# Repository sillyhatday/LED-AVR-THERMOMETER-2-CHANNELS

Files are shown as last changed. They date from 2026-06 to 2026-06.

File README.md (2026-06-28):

# 2 Channel Temperature Monitor

## 📢 Introduction

This came about as a break from the [nixie clock](https://github.com/sillyhatday/IN-12-NIXIE-CLOCK) project that was taking a long time to progress.

It is a 2 channel temperature monitor that is intended for inside and outside temperature monitoring.

>[!NOTE]
>While this project is functional, the code is a mess. It requires a rewrite.

---

## 🔨 Hardware

| Part Description | Part Number | Package | Quantity |
| --- | --- | --- | --- |
| Microcontroller | ATmega8A | DIP-28 | 1 |
| 4x 7 Segment Display | SR420561N | ?? | 1 |
| Voltage Reference | TL431 | TO-92-3 | 1 |
| Temperature Sensor | MCP9700 | TO-92 | 1 |
| Resistors | 470R | L6.3xD2.5xP10.16 | 8 |
| Resistors | 1K | L6.3xD2.5xP10.16 | 1 |
| Resistors | 10K | L6.3xD2.5xP10.16 | 7 |
| Capacitors | 20pF | D3.4xW2.1xP2.5 | 2 |
| Capacitors | 100nF | D3.0xW2.0xP2.5 | 3 |
| Capacitors | 1uF | ?? | 2 |
| Capacitors | 10uF | ?? | 1 |
| Buttons | PS-7054DVB-6PN | ?? | 2 |

---

## 📔 Functional Description

* The sensors used for temperature sensing are two MCP9700 packages. These are easy to use, not requiring external circuit conditioning. These can do negative temperatures without needing negative voltages, using a 500mV offset for 0c.

* For an air temperature monitor, the range does not need to be extreme. For the temperatures expected in Europe, -20c to 50c would be more than enough. For the most part things are between -3c and 35c. The range available for this project is -50c to 154.6c. A span of 204.6c.

* An accurate voltage refernce is needed to compare the sensor voltage with. For this the TL431 is used, it is another easy to use soloution. It has an output of 2.495v. For easy maths (and a large shortcut), having a reference voltage a multiple of the maximum ADC bits makes things simple. The 10-bit ADC is 0 - 1023. Setting the refrence voltage to 2.048v, through the use of a voltage divider network, is close enough to double.

* You may see that the finest change of temperature is 0.2c. That is 2048mV / 1023ADC = 2mV. The MCP9700 sensor output changes 10mV / 1c. As this setup requires 2mV per 1 ADC, 10mV / 2mV = 5. Finally, 5 ADC changes per 1c means, 1c / 5 = 0.2c. Should there not be a nice relation between voltage and ADC, the maths become more involved. Along the lines of: ADC reading > convert ADC to voltage > convert voltage to temperature. This can involve the use of floating point numbers. When getting to oversamlping, this complicates things further.

* The device has a single screen displaying temperature. It has two buttons. One for selecting which sensor is being displayed and the other to cycle through peak readings. These being: indoor high, indoor low, outdoor high & outdoor low. Peak readings are always being updated regardless of what is actively displayed on screen. These values can be reset by shorting the jumper connections on the back of the board. This can also be connected to a button if desired.

* I ended up using a mini 3 pin XLR connector for the outdoor temperature sensor, with the idea of it being removable should I wish to not use it, or I need to disconnect my outdoor sensor that isn't easily movable. I had the indoor sensor inside the case, the thought being it would help filter out any air current that could cause wild temperature reading changes. This did not work as the heat from the MCU was enough to ruin the accuracy. For accurate readings, the sensor should also be on a wire and positioned in the rood so that it is away from strong air currents. There is software averaging to reduce wild display changes.

>[!NOTE]
>The project code is honestly a mess. It's currently half rewritten in a better way using state machines. For now, this works well enough.

>[!TIP]
>Direct sunlight will heat up the outdoor sensor. A screen is required to help reduce this effect.

## ⚫ Progress

### 🟢 Done
- Build a functional temperature monitor that can read two channels
- Implement peak temperature readings and store them into EEPROM
- Add EEPROM check for knowing if to initialise memory space.
- Display text on screen when interacting with the button functions.

### 🟡 Working On
- Rewriting the whole code to use a traditional state machine based structure.
- Removing known bugs.

### ⚪ Next
- Nothing. A whole new project expanding on this one.

### 🔴 Known Bugs
- Temperatures over 100c corrupt adjacent memory space. Needs memory allocations moving.
- Flickering display when using the button functions. Race conditions, the rewrite will fix.
  
---

## Photos

### PCB Render

LED 7 Segment Temperature Monitor Front
LED 7 Segment Temperature Monitor Reart

### Final Concept
Temperature Monitor Enclosure angled front smol
Temperature Monitor Enclosure angled back smol

### Current Build



---

## Tools

- Tools: Arduino IDE 1.8.19 – MiniCore for ATMEGA8

---

## Links

🛍️ Inside Gadgets Shop: https://shop.insidegadgets.com <br>
📎 Inside Gadgets GitHub: https://github.com/insidegadgets <br>
📷 Inside Gadgets Insta: https://www.instagram.com/inside.gadgets <br>
🖇️ Bytendo Mods GitHub: https://github.com/bytendomods <br>
🐭 Bucket Mouse: https://github.com/Bucket-Mouse <br>
🛒 Natalie Shop: https://nataliethenerd.com/ <br>
🤓 Natalie GitHub: https://github.com/natalie-lang/natalie <br>
💡 Danyk Project 1: https://danyk.cz/avr_tep2_en.html <br>
🌡️ Danyk Project 2: https://danyk.cz/avr_tep_en.html <br>

---

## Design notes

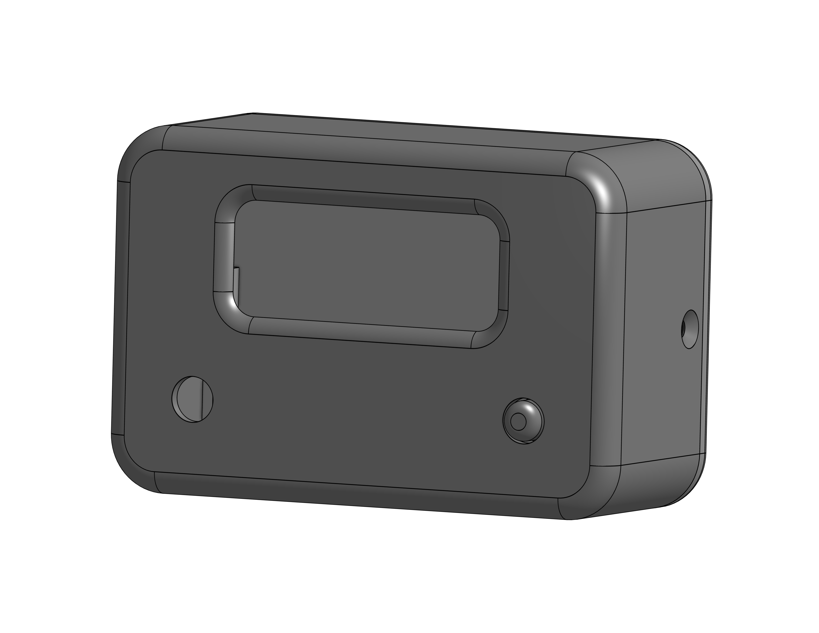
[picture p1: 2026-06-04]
PHOTOS & RENDERS/Temperature Monitor Enclosure angled front.png

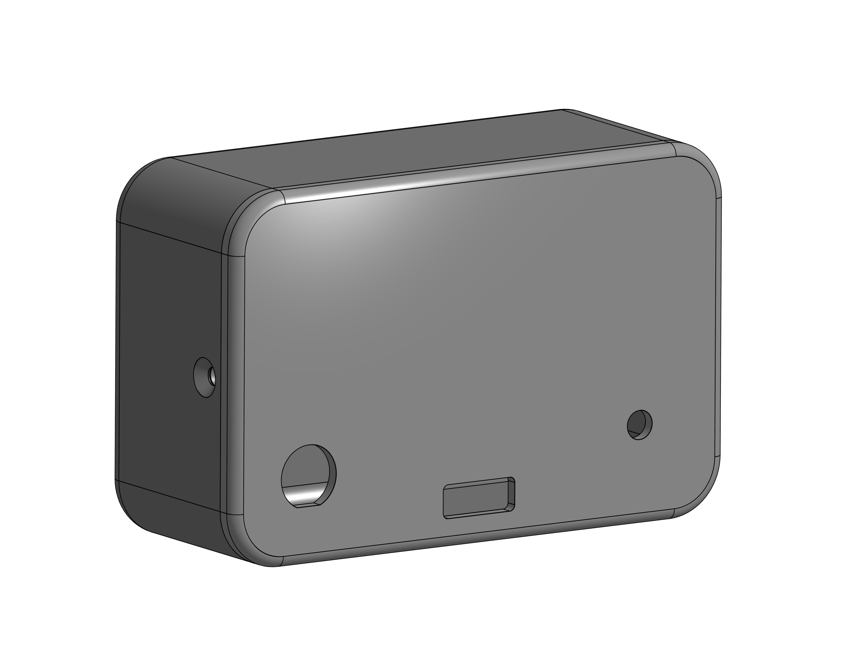
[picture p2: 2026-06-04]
PHOTOS & RENDERS/Temperature Monitor Enclosure angled back.png

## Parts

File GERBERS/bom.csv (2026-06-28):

Designator | Footprint | Quantity | Value | LCSC Part #
C1, C2 | C_Disc_D5.0mm_W2.5mm_P2.50mm | 2 | 100nF
C3 | CP_Radial_D5.0mm_P2.50mm | 1 | 47uF
C4, C5 | C_Disc_D5.0mm_W2.5mm_P2.50mm | 2 | 20pF
C6, C7 | CP_Radial_D4.0mm_P2.00mm | 2 | 1uF
J1, J2 | PinHeader_1x03_P2.54mm_Vertical | 2 | Conn_01x03_Pin
Q1, Q2, Q3, Q4 | TO-92_Inline | 4 | NPN
R1, R12, R2, R3, R4, R5, R6, R7 | R_Axial_DIN0207_L6.3mm_D2.5mm_P10.16mm_Horizontal | 8 | 470R
R10, R11, R13, R14, R8 | R_Axial_DIN0207_L6.3mm_D2.5mm_P10.16mm_Horizontal | 5 | 10K
R9 | R_Axial_DIN0207_L6.3mm_D2.5mm_P10.16mm_Horizontal | 1 | 4K7
SW1, SW2 | SHOU HAN 5.8 WSPT | 2 | SW_DPST
U1 | DIP-28_W7.62mm | 1 | ATmega8A-P
U2 | CA56-12EWA | 1 | CA56-12EWA
U3 | TO-92_Inline | 1 | TL431D
U4, U5 | TO-92_Inline | 2 | MCP9700
Y1 | Crystal_HC18-U_Vertical | 1 | Crystal

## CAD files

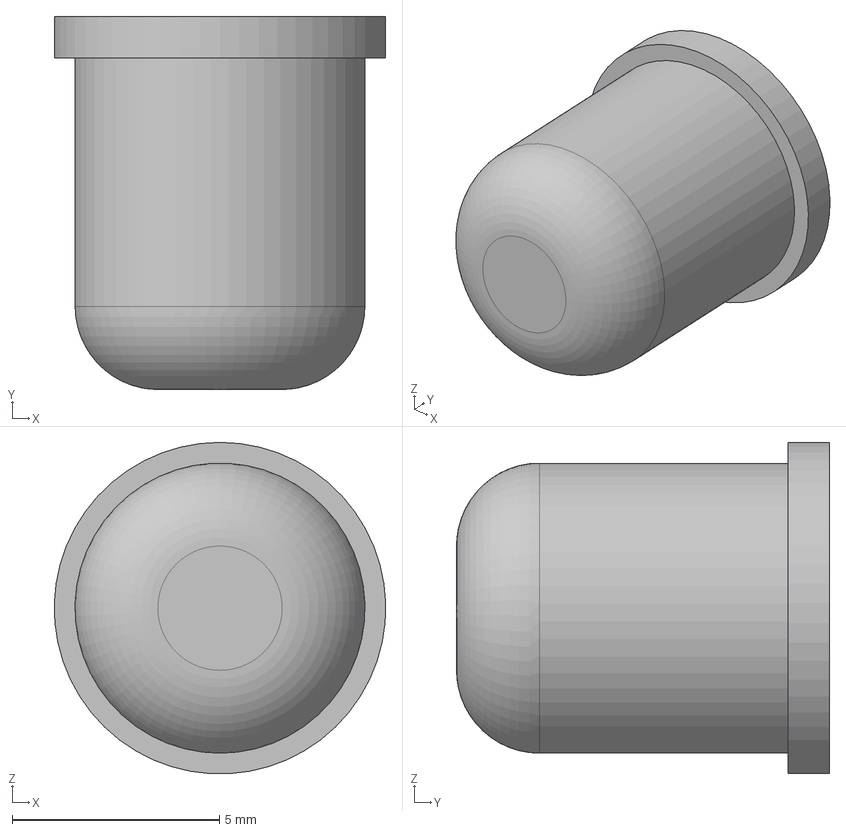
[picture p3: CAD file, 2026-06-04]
3D MODELS/Temperature Monitor Enclosure - Button.step
8.00 x 9.00 x 7.99 mm

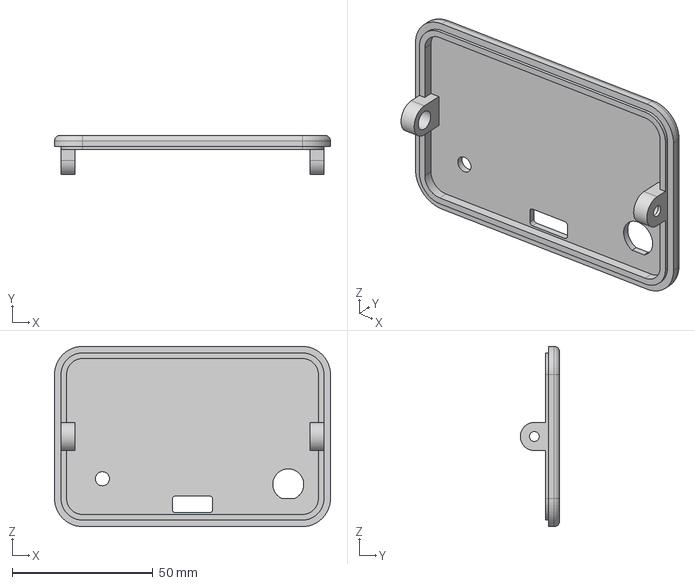
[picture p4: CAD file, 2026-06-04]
3D MODELS/Temperature Monitor Enclosure - Lid.step
98.0 x 14.0 x 64.0 mm

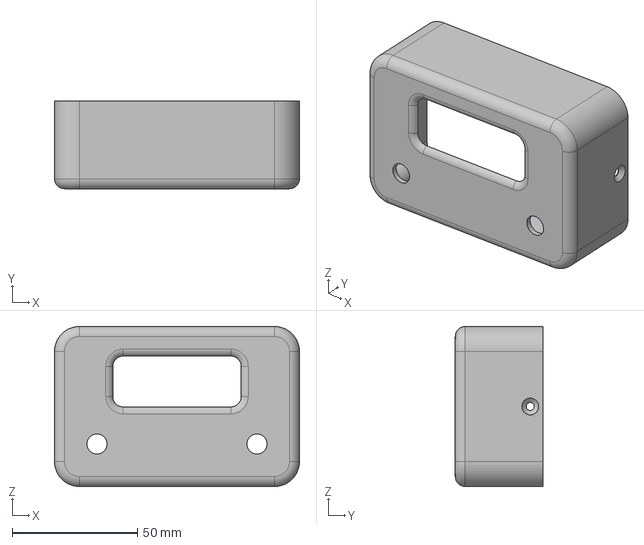
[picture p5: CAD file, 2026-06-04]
3D MODELS/Temperature Monitor Enclosure - Enclosure.step
98.0 x 35.0 x 64.0 mm

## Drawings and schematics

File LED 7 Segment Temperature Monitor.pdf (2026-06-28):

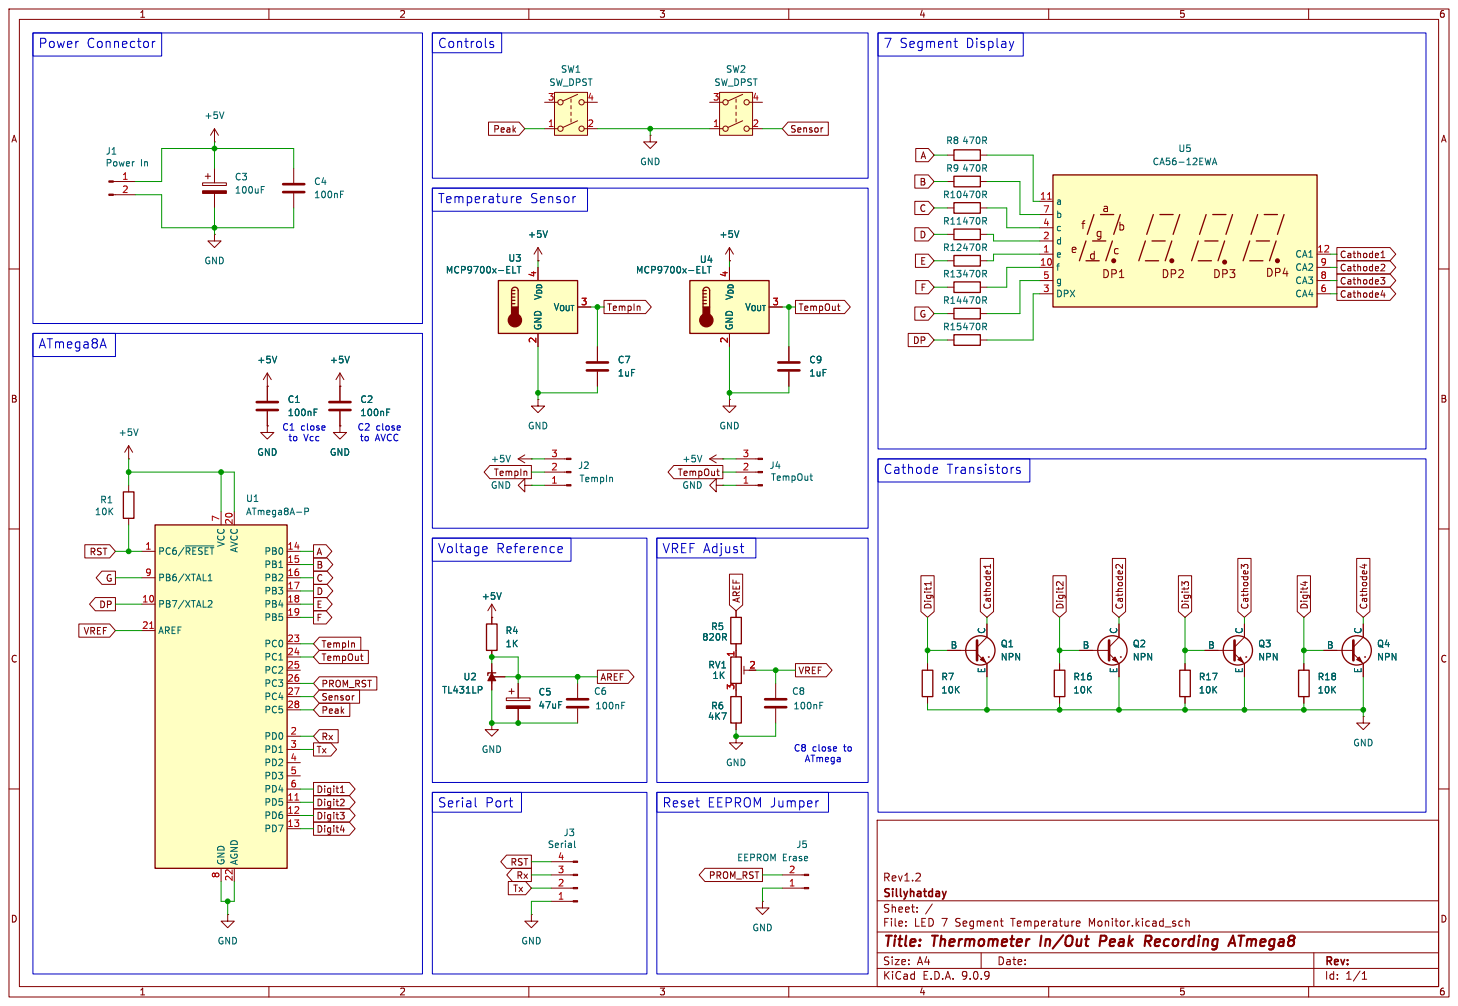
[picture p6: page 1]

Id: 1/1 Title: Thermometer In/Out Peak Recording ATmega8

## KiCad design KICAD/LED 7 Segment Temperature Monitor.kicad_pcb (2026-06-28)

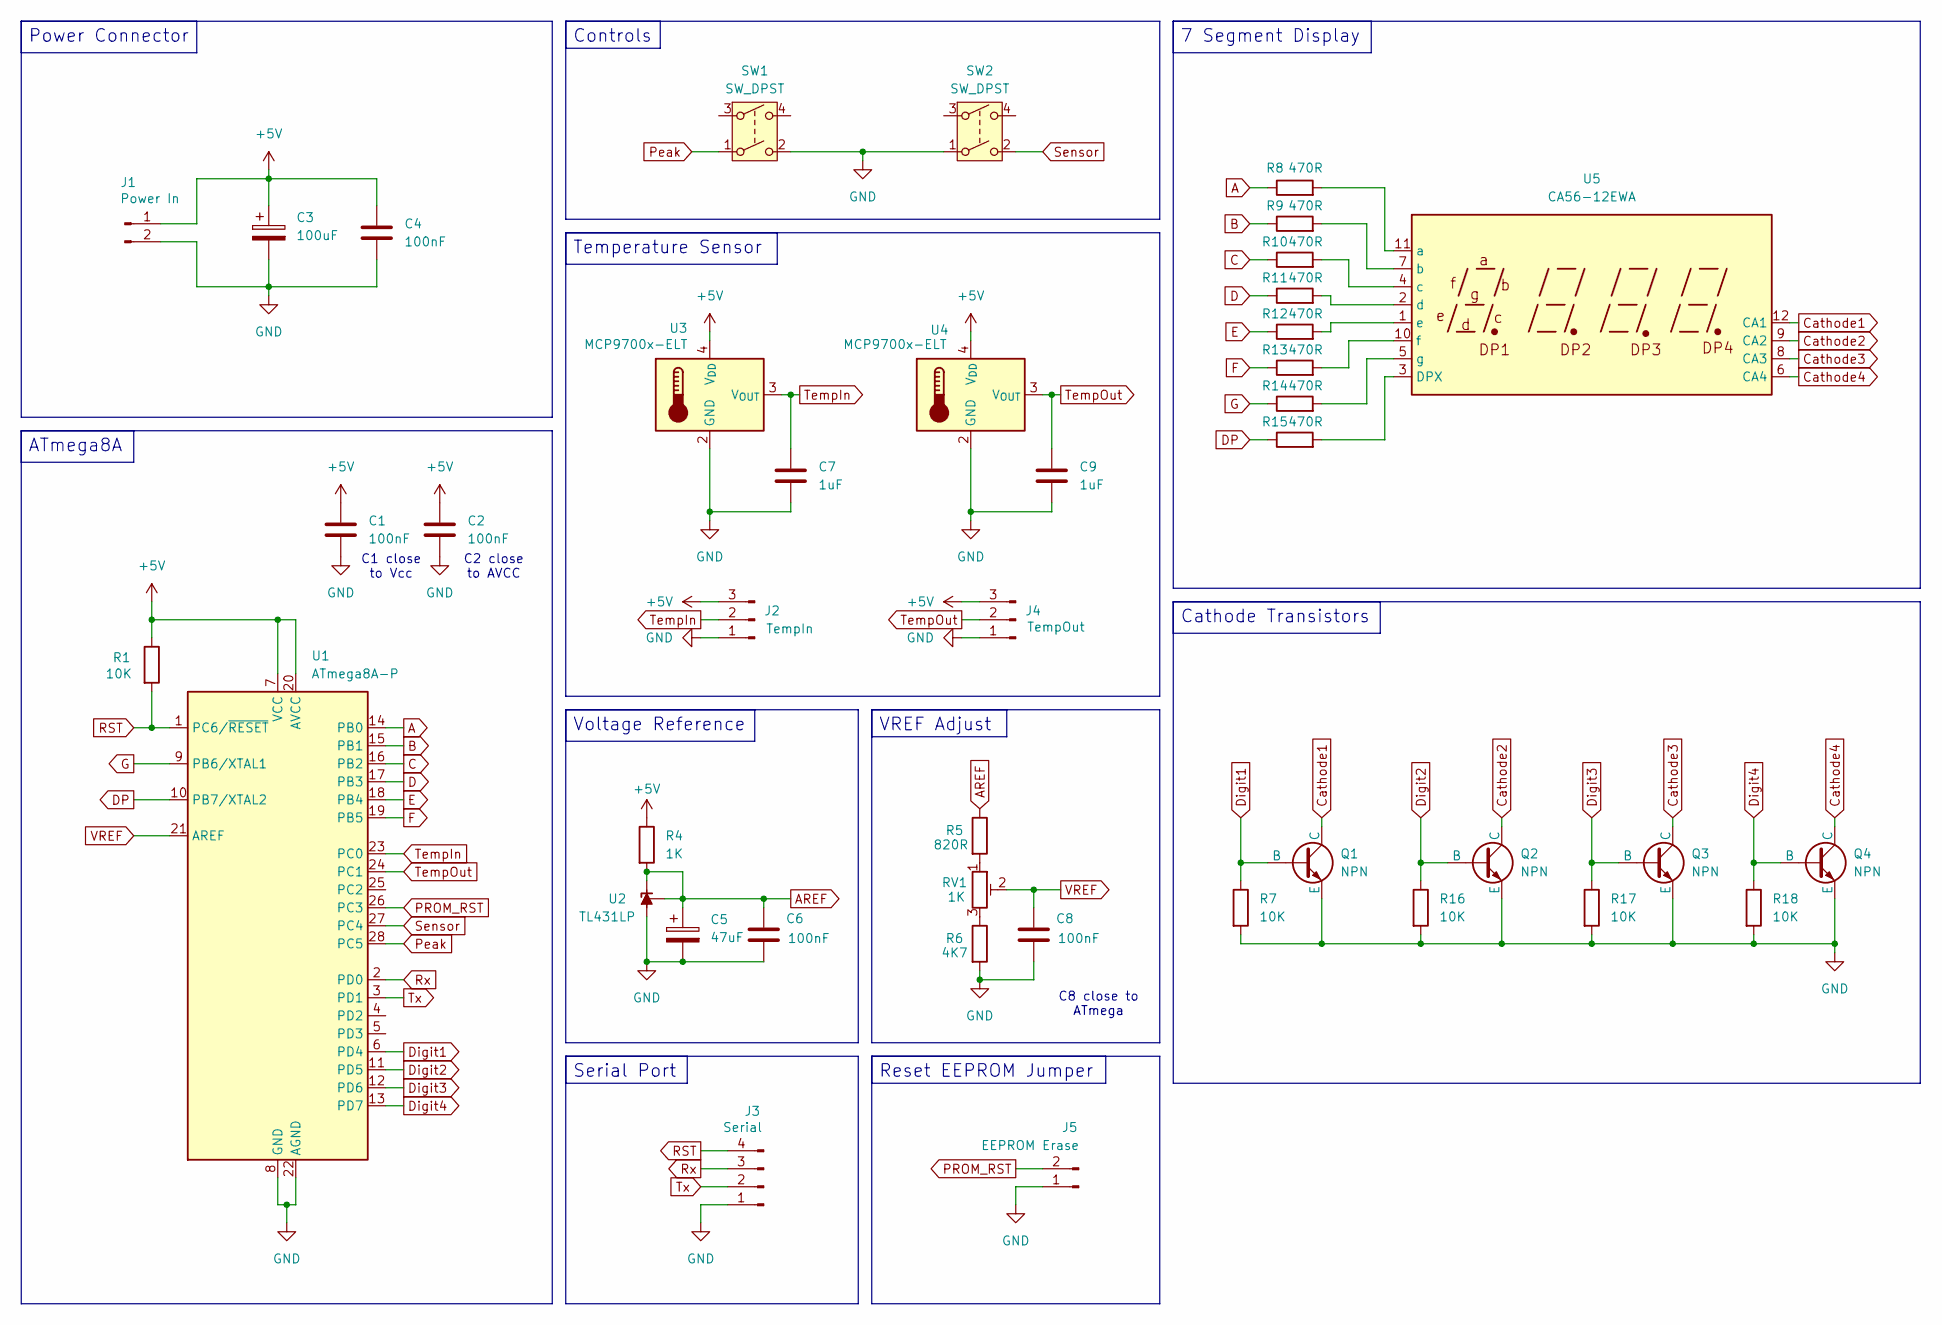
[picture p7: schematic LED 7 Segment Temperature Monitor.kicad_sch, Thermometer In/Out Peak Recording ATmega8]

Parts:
C1, C2, C4, C6, C8: 100nF; C_Disc_D5.0mm_W2.5mm_P2.50mm
C3: 100uF; CP_Radial_D5.0mm_P2.50mm
C5: 47uF; CP_Radial_D5.0mm_P2.50mm
C7, C9: 1uF; C_Disc_D5.0mm_W2.5mm_P2.50mm
J1: Power In; PinHeader_1x02_P2.54mm_Vertical
J2: TempIn; PinHeader_1x03_P2.54mm_Vertical
J3: Serial; PinHeader_1x04_P2.54mm_Vertical
J4: TempOut; PinHeader_1x03_P2.54mm_Vertical
J5: EEPROM Erase; PinHeader_1x02_P2.54mm_Vertical
Q1, Q2, Q3, Q4: NPN; TO-92_Inline
R1, R7, R16, R17, R18: 10K; R_Axial_DIN0207_L6.3mm_D2.5mm_P10.16mm_Horizontal
R4: 1K; R_Axial_DIN0207_L6.3mm_D2.5mm_P10.16mm_Horizontal
R5: 820R; R_Axial_DIN0207_L6.3mm_D2.5mm_P10.16mm_Horizontal
R6: 4K7; R_Axial_DIN0207_L6.3mm_D2.5mm_P10.16mm_Horizontal
R8, R9, R10, R11, R12, R13, R14, R15: 470R; R_Axial_DIN0207_L6.3mm_D2.5mm_P10.16mm_Horizontal
RV1: 1K; Potentiometer_Bourns_3386C_Horizontal
SW1, SW2: SW_DPST; SHOU HAN 5.8 WSPT
U1: ATmega8A-P; DIP-28_W7.62mm_Socket
U2: TL431LP; TO-92_Inline
U3, U4: MCP9700x-ELT
U5: CA56-12EWA

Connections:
+5V: C1.1, C2.1, C3.1, C4.1, J1.1, J2.3, J4.3, R1.1, R4.1, U1.7 (VCC), U1.20 (AVCC), U3.4 (V_{DD}), U4.4 (V_{DD})
A: R8.1, U1.14 (PB0)
AREF: C5.1, C6.1, R4.2, R5.1, U2.1 (REF), U2.3 (K)
B: R9.1, U1.15 (PB1)
C: R10.1, U1.16 (PB2)
Cathode1: Q1.1 (C), U5.12 (CA1)
Cathode2: Q2.1 (C), U5.9 (CA2)
Cathode3: Q3.1 (C), U5.8 (CA3)
Cathode4: Q4.1 (C), U5.6 (CA4)
D: R11.1, U1.17 (PB3)
DP: R15.1, U1.10 (PB7/XTAL2)
Digit1: Q1.2 (B), R7.1, U1.6 (PD4)
Digit2: Q2.2 (B), R16.1, U1.11 (PD5)
Digit3: Q3.2 (B), R17.1, U1.12 (PD6)
Digit4: Q4.2 (B), R18.1, U1.13 (PD7)
E: R12.1, U1.18 (PB4)
F: R13.1, U1.19 (PB5)
G: R14.1, U1.9 (PB6/XTAL1)
GND: C1.2, C2.2, C3.2, C4.2, C5.2, C6.2, C7.2, C8.2, C9.2, J1.2, J2.1, J3.1, J4.1, J5.1, Q1.3 (E), Q2.3 (E), Q3.3 (E), Q4.3 (E), R6.2, R7.2, R16.2, R17.2, R18.2, SW1.2, SW2.1, U1.8 (GND), U1.22 (AGND), U2.2 (A), U3.2 (GND), U4.2 (GND)
unnamed: R5.2, RV1.1
unnamed: R6.1, RV1.3
unnamed: R15.2, U5.3 (DPX)
unnamed: R8.2, U5.11 (a)
unnamed: R9.2, U5.7 (b)
unnamed: R10.2, U5.4 (c)
unnamed: R11.2, U5.2 (d)
unnamed: R12.2, U5.1 (e)
unnamed: R13.2, U5.10 (f)
unnamed: R14.2, U5.5 (g)
PROM_RST: J5.2, U1.26 (PC3)
Peak: SW1.1, U1.28 (PC5)
RST: J3.4, R1.2, U1.1 (PC6/~RESET)
Rx: J3.3, U1.2 (PD0)
Sensor: SW2.2, U1.27 (PC4)
TempIn: C7.1, J2.2, U1.23 (PC0), U3.3 (V_{OUT})
TempOut: C9.1, J4.2, U1.24 (PC1), U4.3 (V_{OUT})
Tx: J3.2, U1.3 (PD1)
VREF: C8.1, RV1.2, U1.21 (AREF)

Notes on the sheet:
C2 close to AVCC
C1 close to Vcc
C8 close to ATmega
7 Segment Display
Power Connector
ATmega8A
Controls
Voltage Reference
Reset EEPROM Jumper
Temperature Sensor
Cathode Transistors
Serial Port
VREF Adjust

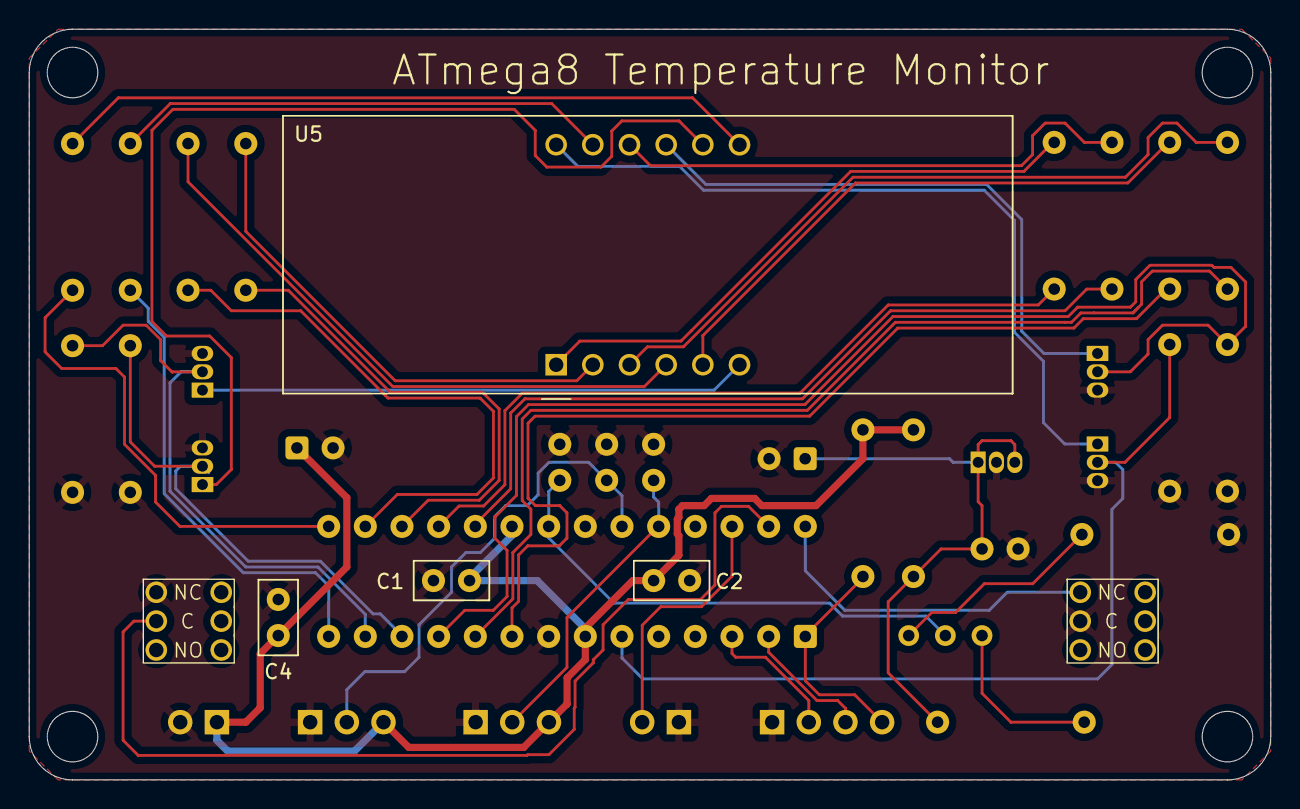
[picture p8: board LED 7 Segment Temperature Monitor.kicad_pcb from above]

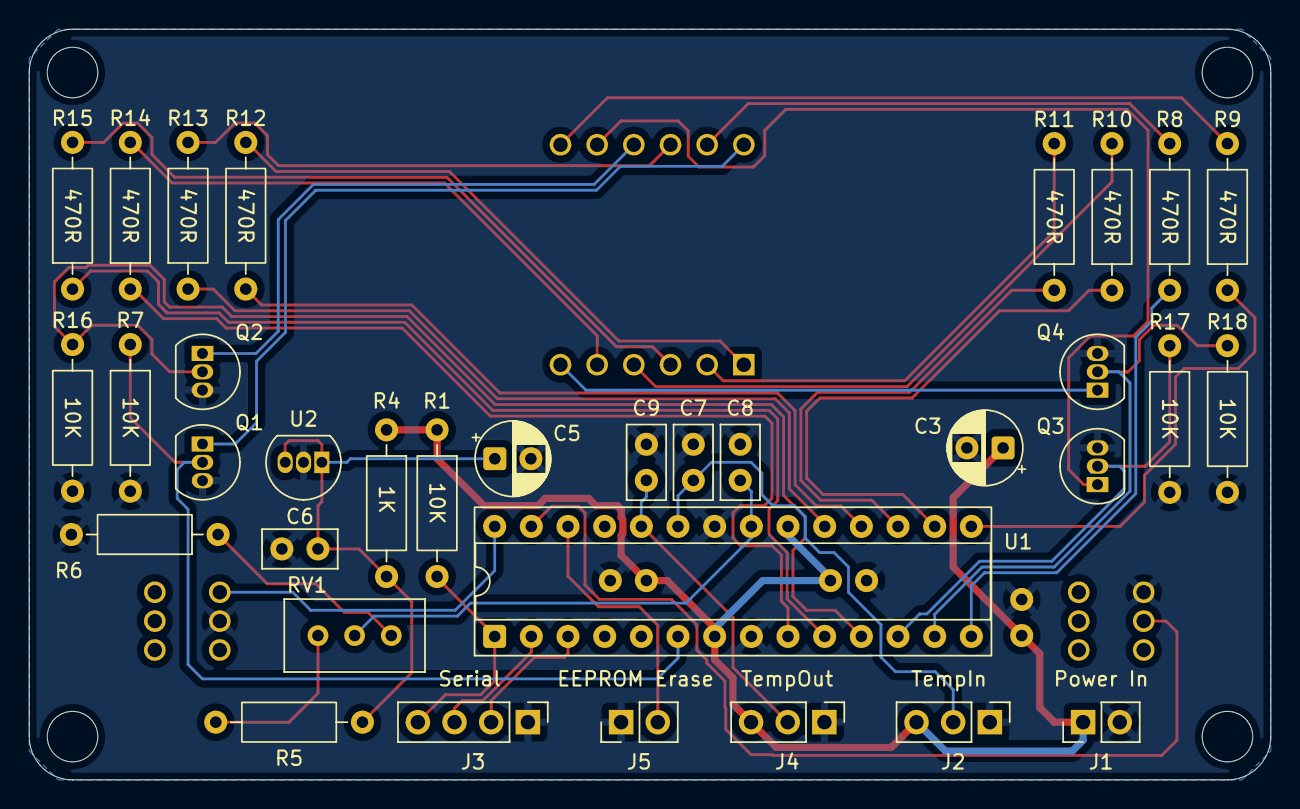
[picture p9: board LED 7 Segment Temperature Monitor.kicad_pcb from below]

Board: 2 copper layers, 86.0 x 52.0 mm, 40 parts (34 on the bottom side), 38 nets.

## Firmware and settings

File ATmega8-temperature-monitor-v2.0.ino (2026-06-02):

// -------------------------------------------------------------------------------------------------------- //
//                                                                                                          //
//                                      ATmega8A 7 Segment Display                                          //
//                                       Temperature Monitor v2.0                                           //
//                                                                                                          //
// -------------------------------------------------------------------------------------------------------- //

// Todo List:
// Use internal clock, not external to clear port B pins (DONE)
// Move all anode output pins to port B. Pins 14, 15, 16, 17, 18, 19, 9 & 10. PB0 - 7 (DONE)
// Move all cathode pins to port D. Pins 4, 5, 6, 11, 12, 13. PD2 - 7 (Already done)
// Sort out EEPROM data overflow. Max temp is 3 digits not 2.
// Change ADC sampling rate to counter based on ISR not time.
// Pressing PEAK while IN / OUT text is shown glitches the display.
// Check what the reset eeprom function does when other text is shown.
// Look up table to replace large switches.

// ***************************************** Include/Define *********************************************** //

#include <EEPROM.h>
//#include <avr/string.h>
#include <avr/io.h>
#include <avr/interrupt.h>
#include <avr/sleep.h>

// **************************************** Button Constants ********************************************** //

const byte INDOOR_SENSOR =                           A0;                         // Sensor inside input pin
const byte OUTDOOR_SENSOR =                          A1;                         // Sensor outside input pin
const byte SELECT =                                  A4;                         // Sensor select button
const byte PEAK =                                    A5;                         // Peak value display
const byte RESET =                                   A3;                         // Clear EEPROM jumper
const byte DEBOUNCE_DELAY =                         250;                         // Button debounce millis

// **************************************** EEPROM Constants ********************************************** //

const byte EEPROM_ADDRESS_SIGNITURE =                 0;                         // EEPROM initialised
const byte EEPROM_ADDRESS_IN_HIGH =                   1;                         // Indoor temp high
const byte EEPROM_ADDRESS_IN_LOW =                    3;                         // Indoor temp low
const byte EEPROM_ADDRESS_OUT_HIGH =                  5;                         // Outdoor temp high
const byte EEPROM_ADDRESS_OUT_LOW =                   7;                         // Outdoor temp low
const byte EEPROM_ADDRESS_IN_OR_OUT =                 9;                         // Last sensor displayed
const byte EEPROM_DATA_SIGNITURE =                 0x55;                         // EEPROM initialised data
const int EEPROM_DELAY =                           6000;                         // millis to prevent garbage on boot

// **************************************** Display Constants ********************************************* //

const byte NUM_DISPLAYS =                             4;
const byte NUM_SEGMENTS =                             7;
const uint16_t DISPLAY_TIME =                      2000;                         // Time to show which sensor is selected
const uint16_t DISPLAY_TIME_SHORT =                1000;

// **************************************** Sensor Constants ********************************************** //

const byte AVERAGE_SAMPLE_TIME =                      5;                         // heartBeat count (20s)
const int SAMPLE_INTERVAL =                        4000;                         // Sample frequency ms
const byte SAMPLE_NUM =                              64;
const byte SAMPLE_SHIFT =                             5;
const byte CALIBRATION_IN =                          10;
const byte CALIBRATION_OUT =                         10;

// ***************************************** Character Data ********************************************** //

const byte ANODES[22] = {                 // DP GFEDCBA
                                             0b00111111,                         // 0
                                             0b00000110,                         // 1
                                             0b01011011,                         // 2
                                             0b01001111,                         // 3
                                             0b01100110,                         // 4
                                             0b01101101,                         // 5
                                             0b01111101,                         // 6
                                             0b00000111,                         // 7
                                             0b01111111,                         // 8
                                             0b01101111,                         // 9
                                             0b00000000,                         // 10 OFF
                                             0b01000000,                         // 11 -
                                             0b01011000,                         // 12 c
                                             0b01011001,                         // 13 c with top mark
                                             0b00110000,                         // 14 I
                                             0b00111110,                         // 15 U
                                             0b00110111,                         // 16 n
                                             0b00000001,                         // 17 Top -
                                             0b01110110,                         // 18 H
                                             0b00111000,                         // 19 L
                                             0b01111001,                         // 20 E
                                             0b01111000                          // 21 t
};
const byte CATHODES[4] = {
                                             0b10000000,                         // Display 1
                                             0b01000000,                         // Display 2
                                             0b00100000,                         // Display 3
                                             0b00010000,                         // Display 4
};
const byte DECIMAL =                         0b10000000;                         // Decimal

const byte DISPLAY_OFF =                             10;                         // Human readable display references
const byte DISPLAY_MINUS =                           11;
const byte DISPLAY_C =                               12;
const byte DISPLAY_C_MINUS =                         13;
const byte DISPLAY_I =                               14;
const byte DISPLAY_U =                               15;
const byte DISPLAY_N =                               16;
const byte DISPLAY_TOP_MINUS =                       17;
const byte DISPLAY_H =                               18;
const byte DISPLAY_L =                               19;
const byte DISPLAY_E =                               20;
const uint8_t DISPLAY_T =                            21;

// **************************************** EEPROM Variables ************************************************* //

uint8_t eepromClear =                             false;                         // Is the EEPROM empty?
int16_t eepromDataRam[4] =                 {0, 0, 0, 0};                         // EEPROM data loaded into RAM

// **************************************** Display Variables ************************************************ //

uint16_t peakDataValue =                              0;                         // Peak value to show
uint8_t digits[4] =                        {0, 0, 0, 0};                         // Main display buffer
uint8_t live[4] =                          {0, 0, 0, 0};                         // Live temperature reading
uint8_t text[4] =                          {0, 0, 0, 0};                         // Text buffer
uint8_t peak[4] =                          {0, 0, 0, 0};                         // Peak value buffer
uint8_t currentDigit =                                0;                         // Active digit on display now
uint32_t showTextStart =                              0;                         // Time when showing sensor info started
uint32_t showValuesStart =                            0;

// **************************************** Sensor Variables ************************************************* //

int16_t signedIndoorTemperature =                     0;                         // Indoor temperature celcius x10
int16_t signedOutdoorTemperature =                    0;                         // Outdoor temperature celcius x10
volatile uint16_t heartBeat =                         0;                         // Sensor sample freq

// ***************************************** Button Variables ********************************************* //

uint8_t resetButtonState =                           false;
uint8_t resetButtonStatePrev =                       false;
uint8_t selectButtonState =                          false;
uint8_t selectButtonStatePrev =                      false;
uint8_t peakButtonState =                            false;
uint8_t peakButtonStatePrev =                        false;
uint32_t buttonReferenceTime =                           0;
uint32_t buttonPreviousPushTime =                        0;

// ***************************************** Global Variables ********************************************* //

uint32_t previousMicros =                                  0;                         // Last update time of display micros
uint32_t previousMillis =                                  0;                         // Last update time of sensor reading
uint16_t rollingAverageIndoor[8] =  {0, 0, 0, 0, 0, 0, 0, 0};                         // Average for stability
uint16_t rollingAverageOutdoor[8] = {0, 0, 0, 0, 0, 0, 0, 0};                         // Average for stability
uint16_t rollingAverageIndoorValue =                       0;
uint16_t rollingAverageOutdoorValue =                      0;
uint8_t rollingAverageIndex =                              0;
uint8_t rollingAverageFull =                           false;
uint16_t takeAverageSample =                               0;
uint8_t modeChangeBlock =                              false;

// ========================================== Enumerations ================================================ //

  typedef enum {
    MODE_LIVE,
    MODE_TEXT,
    MODE_PEAK
  } SystemState;

  typedef enum {
    TEXT_IN,
    TEXT_OUT,
    TEXT_IN_LOW,
    TEXT_IN_HIGH,
    TEXT_OUT_LOW,
    TEXT_OUT_HIGH,
    TEXT_RESET,
    TEXT_BLANK
  } Text;

  typedef enum {
    SENSOR_IN,
    SENSOR_OUT
  } Transducers;

  SystemState modeCurrent = MODE_LIVE;
  SystemState modeRequest = MODE_LIVE;
  SystemState modeReturn = MODE_LIVE;
  Text textCurrent = TEXT_BLANK;
  Text peakMenuPosition = TEXT_IN_LOW;
  Transducers sensorCurrent = SENSOR_IN;
  Transducers sensorRequest = SENSOR_IN;

// ^^^^^^^^^^^^^^^^^^^^^^^^^^^^^^^^^^^^^^^^^^^^ Functions ^^^^^^^^^^^^^^^^^^^^^^^^^^^^^^^^^^^^^^^^^^^^^^^^^ //

void setup(void);
void loop(void);
void eepromInitialiser(void);


// ============================================== Setup =================================================== //

void setup() {

// ADC Reference
  analogReference(EXTERNAL);

// PORTB Setup - Anodes            -     Arduino Pin -> 8, 9, 10, 11, 12, 13, PB6, PB7  -  Port Pin: PB7...0
  DDRB = 0b11111111;
  PORTB = 0b00000000;

// PORTC Setup - Sensors/Buttons   -     Arduino Pin -> A0, A1, A3, A4, A5  -  Port Pin: PC0, PC1, PC3, PC4, PC5
  DDRC = 0b00000000;
  PORTC = 0b00111100;

// PORTD Setup - Cathodes          -     Arduino Pin -> 7, 6, 5, 4   -   Port Pin: PD7...4
  DDRD = 0b11110000;
  PORTD = 0b00001111;

  set_sleep_mode(SLEEP_MODE_IDLE);
  sleep_enable();

  for (int i = 0; i < 4; i++) {
    digits[i] = DISPLAY_MINUS;
  }
  
  eepromInitialiser();

  cli();
  TCCR2 = 0;
  TCNT2 = 0;
  OCR2 = 124;
  TCCR2 |= (1 << WGM21)|(1 << CS21);
  TIMSK |= (1 << OCIE2);
  sei();
  
}
// ======================================== Timer2 Interrupt ============================================== //

ISR(TIMER2_COMP_vect) {
  heartBeat++;
  multiplex();

}
// ============================================== Main ==================================================== //

void loop() {
  /*
  buttonReferenceTime = millis();

  buttonHandler(SELECT, selectButtonState, selectButtonStatePrev, buttonReferenceTime, buttonPreviousPushTime);
  buttonHandler(PEAK, peakButtonState, peakButtonStatePrev, buttonReferenceTime, buttonPreviousPushTime);
  buttonHandler(RESET, resetButtonState, resetButtonStatePrev, buttonReferenceTime, buttonPreviousPushTime);

  cli();
  int hb = heartBeat;
  sei();

  if (hb >= SAMPLE_INTERVAL) {
    heartBeat = 0;
    takeAverageSample++;
    sensorReading();
    peakValues(rollingAverageIndoorValue, eepromDataRam[0], EEPROM_ADDRESS_IN_HIGH, true);
    peakValues(rollingAverageIndoorValue, eepromDataRam[1], EEPROM_ADDRESS_IN_LOW, false);
    peakValues(rollingAverageOutdoorValue, eepromDataRam[2], EEPROM_ADDRESS_OUT_HIGH, true);
    peakValues(rollingAverageOutdoorValue, eepromDataRam[3], EEPROM_ADDRESS_OUT_LOW, false);
  }
  */
  systemState();
  displayBufferSelect();

  if (modeCurrent == MODE_TEXT) {
    if (millis() - showTextStart >= DISPLAY_TIME) {
      modeRequest = modeReturn;
      modeChangeBlock = false;
    }
  }

  if (modeCurrent == MODE_PEAK) {
    if (millis() - showValuesStart >= DISPLAY_TIME_SHORT) {
      modeRequest = modeReturn;
      modeChangeBlock = false;
    }
  }
}
// =========================================== Main State ================================================= //

void systemState() {

  if (modeCurrent != modeRequest) {
    switch (modeRequest) {
      case MODE_LIVE:
        modeCurrent = MODE_LIVE;
        // do a thing
        break;
      case MODE_TEXT:
        modeCurrent = MODE_TEXT;
        modeChangeBlock = true;
        break;
      case MODE_PEAK:
        modeCurrent = MODE_PEAK;
        modeChangeBlock = true;
        break;
    }
  }
}
// =========================================== Display Buffer ============================================= //

void displayBufferSelect() {

  switch (modeCurrent) {
    case MODE_LIVE:
      liveDisplayBuffer();
      memcpy(digits, live, 4);
      break;
    case MODE_TEXT:
      textDisplayBuffer(textCurrent);
      memcpy(digits, text, 4);
      break;
    case MODE_PEAK:
      peakDisplayBuffer();
      memcpy(digits, peak, 4);
      break;
  }
}
// ========================================== Button Handler ============================================== //

void buttonHandler(byte avrPin, bool &buttonState, bool &buttonStatePrevious, unsigned long currentReferenceTime, unsigned long &buttonPushPreviousTime) {

  buttonState = !digitalRead(avrPin);

  if (buttonState && !buttonStatePrevious && (currentReferenceTime - buttonPushPreviousTime > DEBOUNCE_DELAY)) {
    switch (avrPin) {
      case SELECT:
        selectButton();
        break;
      case PEAK:
        peakButton();
        break;
      case RESET:
        resetButton();
        break;
    }
    buttonPushPreviousTime = currentReferenceTime; 
  }
  buttonStatePrevious = buttonState;
}
// =========================================== Select Button ============================================== //

void selectButton() {

  if (modeChangeBlock) {
    return;
  }
  
  sensorCurrent = (sensorCurrent == SENSOR_IN) ? SENSOR_OUT : SENSOR_IN;           // toggle sensor

  if (sensorCurrent == SENSOR_IN) {
    textCurrent = TEXT_IN;
  } else {
    textCurrent = TEXT_OUT;
  }
  modeReturn = MODE_LIVE;
  modeRequest = MODE_TEXT;
  showTextStart = millis();
}
// ============================================ Peak Button =============================================== //

void peakButton() {

  if (modeChangeBlock) {
    return;
  }
  
  peakMenuPosition = nextPeakState(peakMenuPosition);
  textCurrent = peakMenuPosition;
  modeReturn = MODE_PEAK;
  modeRequest = MODE_TEXT;
  showTextStart = millis();
}
// ========================================== Reset Button ================================================ //

void resetButton() {

  
}
// ========================================== Peak Menu Index ============================================= //

Text nextPeakState(Text index) {
  
  switch (index) {
    case TEXT_IN_LOW:
      return TEXT_IN_HIGH;
    case TEXT_IN_HIGH:
      return TEXT_OUT_LOW;
    case TEXT_OUT_LOW:
      return TEXT_OUT_HIGH;
    case TEXT_OUT_HIGH:
      return TEXT_IN_LOW;
    default:
      return TEXT_IN_LOW;
  }
}
// ========================================= EEPROM Initialiser =========================================== //

void eepromInitialiser() {

  if ((EEPROM.read(EEPROM_ADDRESS_SIGNITURE) != EEPROM_DATA_SIGNITURE) || (eepromClear)) {
    eepromClear = false;
    
    for (byte i = 1; i < 3; i++) {
      EEPROM.write(i, -50);
    }
    for (byte i = 3; i < 5; i++) {
      EEPROM.write(i, 50);
    }
    for (byte i = 5; i < 7; i++) {
      EEPROM.write(i, -50);
    }
    for (byte i = 7; i < 9; i++) {
      EEPROM.write(i, 50);
    }
    EEPROM.write(EEPROM_ADDRESS_IN_OR_OUT, 0);    
    EEPROM.write(EEPROM_ADDRESS_SIGNITURE, EEPROM_DATA_SIGNITURE);
  }

  if (EEPROM.read(EEPROM_ADDRESS_SIGNITURE) != EEPROM_DATA_SIGNITURE) {
    for (int i = 0; i < 4; i++) {
      eepromDataRam[i] = 99;
    }
  }
  if (EEPROM.read(EEPROM_ADDRESS_SIGNITURE) == EEPROM_DATA_SIGNITURE) {
    EEPROM.get(EEPROM_ADDRESS_IN_HIGH, eepromDataRam[0]);
    EEPROM.get(EEPROM_ADDRESS_IN_LOW, eepromDataRam[1]);
    EEPROM.get(EEPROM_ADDRESS_OUT_HIGH, eepromDataRam[2]);
    EEPROM.get(EEPROM_ADDRESS_OUT_LOW, eepromDataRam[3]);
  }
}

// ============================================ Multiplex ================================================= //

void multiplex() {

  byte num = digits[currentDigit];
  byte anodes = ANODES[num];
  byte cathodes = CATHODES[currentDigit];

  PORTD = 0;
  PORTB = anodes;
  PORTD = cathodes;
  currentDigit++;

  if (currentDigit >= NUM_DISPLAYS) {
    currentDigit = 0;
  }
}
// ========================================= Live Display Buffer ========================================== //

void liveDisplayBuffer() {

  
}
// ========================================= Text Display Buffer ========================================== //

void textDisplayBuffer(Text textToDisplay) {

  switch (textToDisplay) {
    case TEXT_IN:
      text[3] = DISPLAY_OFF;
      text[2] = DISPLAY_I;
      text[1] = DISPLAY_N;
      text[0] = DISPLAY_OFF;
      break;
    case TEXT_OUT:
      text[3] = 0;
      text[2] = DISPLAY_U;
      text[1] = DISPLAY_T;
      text[0] = DISPLAY_OFF;
      break;
    case TEXT_IN_LOW:
      text[3] = DISPLAY_I;
      text[2] = DISPLAY_N;
      text[1] = DISPLAY_OFF;
      text[0] = DISPLAY_L;
      break;
    case TEXT_IN_HIGH:
      text[3] = DISPLAY_I;
      text[2] = DISPLAY_N;
      text[1] = DISPLAY_OFF;
      text[0] = DISPLAY_H;
      break;
    case TEXT_OUT_LOW:
      text[3] = 0;
      text[2] = DISPLAY_U;
      text[1] = DISPLAY_T;
      text[0] = DISPLAY_L;
      break;
    case TEXT_OUT_HIGH:
      text[3] = 0;
      text[2] = DISPLAY_U;
      text[1] = DISPLAY_T;
      text[0] = DISPLAY_H;
      break;
    case TEXT_RESET:
      text[3] = 5;
      text[2] = DISPLAY_E;
      text[1] = DISPLAY_T;
      text[0] = DISPLAY_OFF;
      break;
    case TEXT_BLANK:
      text[3] = DISPLAY_OFF;
      text[2] = DISPLAY_OFF;
      text[1] = DISPLAY_OFF;
      text[0] = DISPLAY_OFF;
      break;
  }
}
// ========================================= Peak Display Buffer ========================================== //

void peakDisplayBuffer() {

  switch (textCurrent) {
    case TEXT_IN_LOW:
      tempToDigitsPeak(eepromDataRam[1]);
      break;
    case TEXT_IN_HIGH:
      tempToDigitsPeak(eepromDataRam[0]);
      break;
    case TEXT_OUT_LOW:
      tempToDigitsPeak(eepromDataRam[3]);
      break;
    case TEXT_OUT_HIGH:
      tempToDigitsPeak(eepromDataRam[2]);
      break;
  }
}
// ============================================ Data Divider ============================================== //

void tempToDigitsPeak(int16_t dataIn) {

  int16_t x = dataIn;

  peak[3] = (x / 100) % 10;
  peak[2] = ((x / 10) % 10) | DECIMAL;
  peak[1] = x % 10;

  if (dataIn < 0) {
    peak[0] = DISPLAY_C_MINUS;
  } else {
    peak[0] = DISPLAY_C;
  }
}
// ============================================ Data Divider ============================================== //

void tempToDigitsLive(uint16_t dataIn) {
  
  int16_t x = dataIn;

  live[3] = (x / 100) % 10;
  live[2] = ((x / 10) % 10) | DECIMAL;
  live[1] = x % 10;

  if (dataIn < 0) {
    live[0] = DISPLAY_C_MINUS;
  } else {
    live[0] = DISPLAY_C;
  } 
}
// ========================================= Celcius Conversion =========================================== //

int analogConversion(byte sensorPin) {

  long sum = 0;
  long voltage = 0;
  long temp = 0;
  analogRead(sensorPin);
                                      
  for (byte i = 0; i < SAMPLE_NUM; i++) {
    sum += analogRead(sensorPin);                // 254 + 255 + 253 + 255 = 1017
  }

  voltage = sum >> SAMPLE_SHIFT;            // 1017 / 2 = 509 (508.5)
  if (sensorPin == INDOOR_SENSOR) {
    temp = (voltage - (500 + CALIBRATION_IN));    // 509 - 500 = 9
  } else {
    temp = (voltage - (500 + CALIBRATION_OUT));
  }

  return temp;
}
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
